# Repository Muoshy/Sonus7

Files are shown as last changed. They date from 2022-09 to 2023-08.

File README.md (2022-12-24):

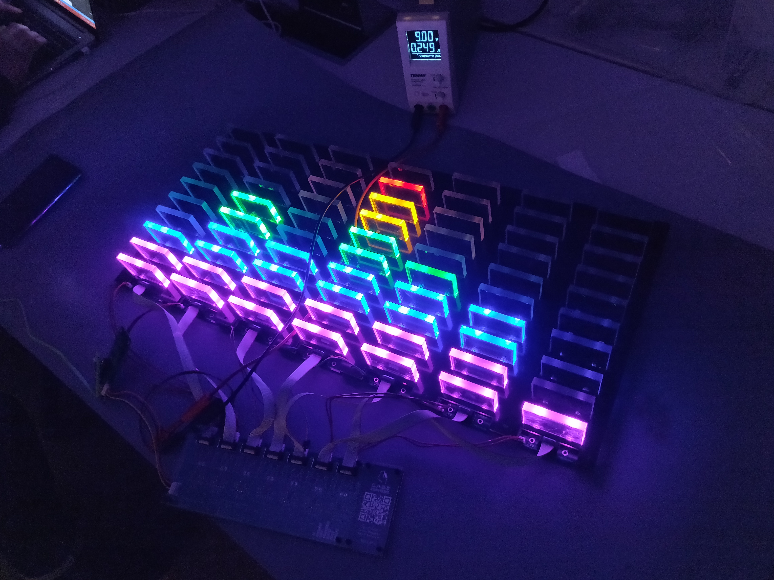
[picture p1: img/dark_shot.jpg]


# Sonus7
  Sonus7 is an analog seven-band spectrum bargraph with op amps. It consists of seven VU-meters, each being fed with a bandpass filter and peak detector circuit. 
  
  Each band has a spacing of 1.25 octaves. The bands are: 63 Hz, 160 Hz, 400 Hz, 1.25 kHz, 2.5 kHz, 6.25 kHz, 16 kHz. 
  
  The filters are second-order Multiple Feedback bandpass filters using TLC272 opamps. The VU-meters consist of a logaritmic comparator array, also using TLC272 opamps. The project is inspired by a reel of 2000 TLC272 bought cheaply at an auction.
  
# Features
- Fully analog (Except input stage)
- Seven frequency bands
- 10 levels per band
- 1.25 octave spacing
- 63 Hz to 16 kHz frequency range

# Filters
The filters were chosen to be Multiple Feedback filters since they allow independent adjustment of the gain $A_m$, filter quality $Q$ and mid frequency $f_m$. The transfer function and equations for calculating component values are taken from TI's design reference SLOD006B (16-31).

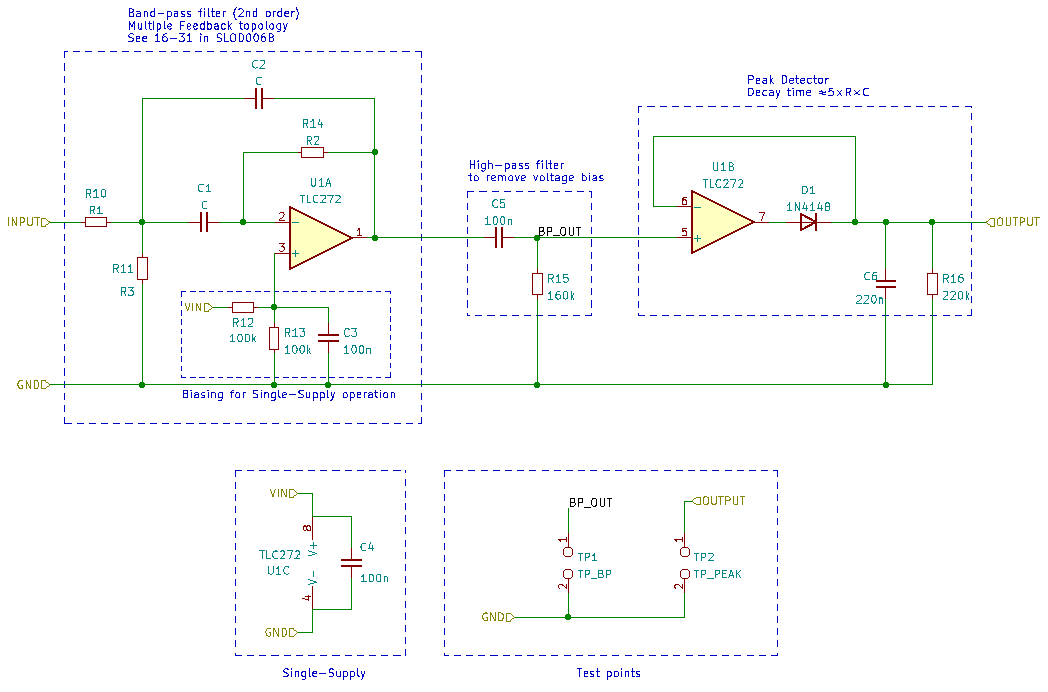
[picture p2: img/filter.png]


The gain and filter quality were set to $A_m = -10, \: Q = 6$ while capacitor values were chosen in the range of 33 to 0.33 nF to end up with reasonable resistor values. A MATLAB script is provided to calculate the exact resistor values and then round to nearest corresponding value from the E-24 series. The frequency responses are then simulated for the exact and rounded resistor values.

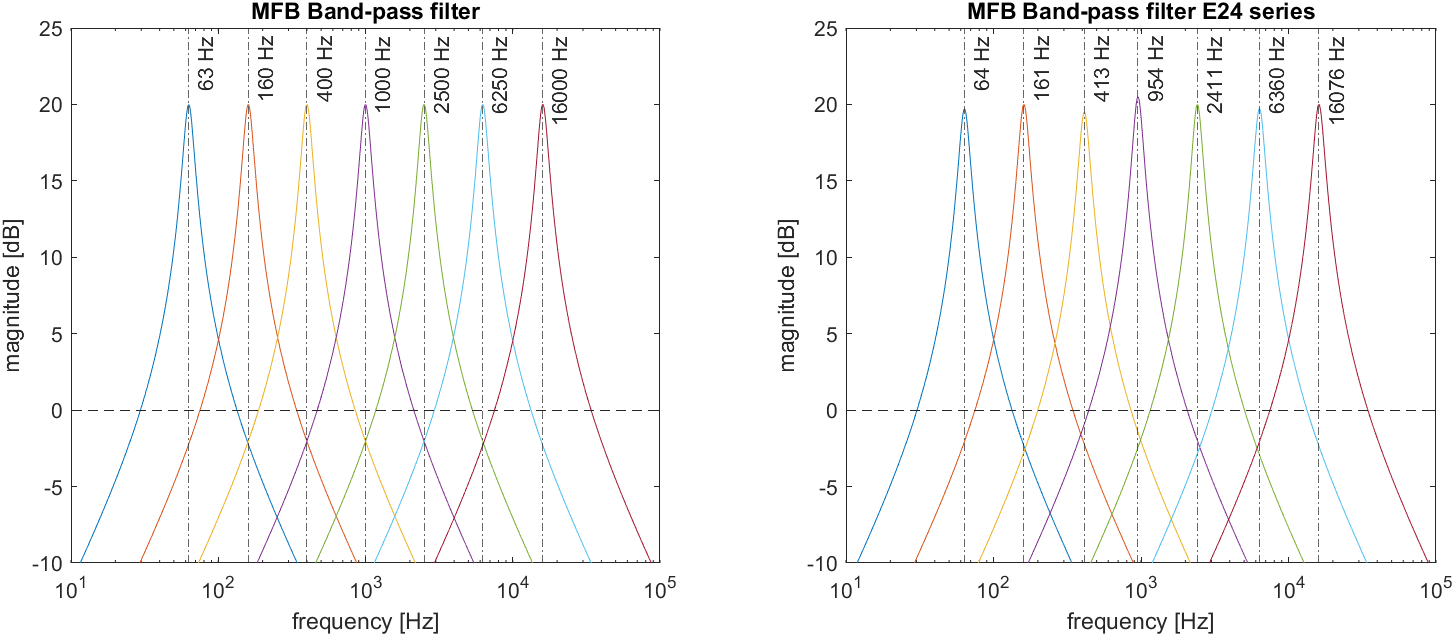
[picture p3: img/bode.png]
bode


A final calculation is done to ensure the filter gains do not exceed the unity gain bandwidth (GBW) of the op amps. The actual amplification from the op amps is obtained from the noise gain. The noise gain is then multiplied with the corresponding mid frequency of each filter to obtain the (highest) GBW. This is also provided in the same MATLAB script. The calculation shows that all filters have a GBW below 2 MHz (TLC272), although the 16 kHz filter is close at 1.1 MHz. Thus, variations in temperature or other factors might limit the gain for 16 kHz filter and cause distortions.

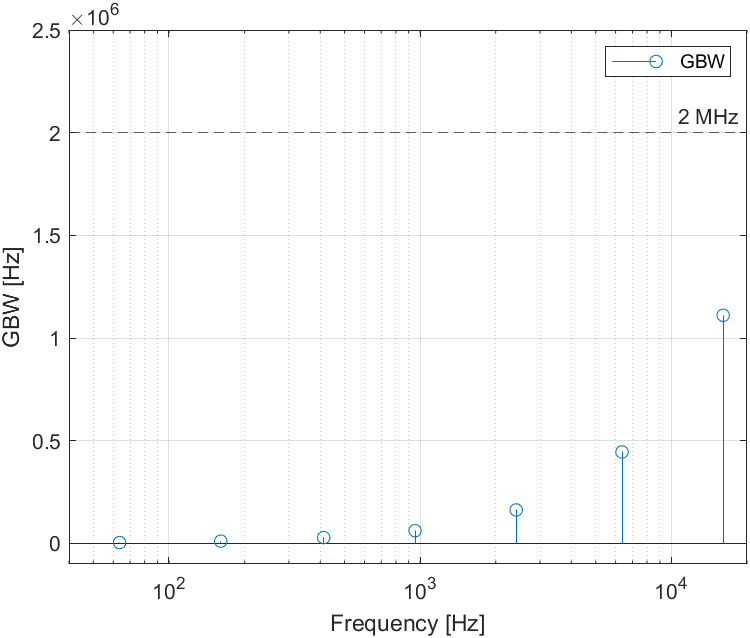
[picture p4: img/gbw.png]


The filtered signals are fed into peak detectors to obtain the audio level for each. The audio levels are then fed into the comparators which control the LEDs.

# Comparators
The comparators are built from open loop op amps. Reference voltage levels are generated from a logarithmic resistor divider (3 dB per step) and fed into the non-inverting inputs, essentially a logarithmic [Kelvin divider](https://en.wikipedia.org/wiki/Kelvin%E2%80%93Varley_divider). The inverting input is fed with the audio level. The op amp output can now function as a current sink for the LEDs. Any time the audio level exceeds the reference voltage level, the output is pulled low, allowing current flow for that level. Each op-amp drives one level, resulting in 70 op amps in total for the comparator stage.

# Construction


## PCBs
The Sonus7 consists of three boards (types).
### Input Stage
 The input stage consists of a custom board with an ESP32 and PCM5100. The ESP32 recieves the audio wirelessly through snapcast, using the port by [@CarlosDerSeher](https://github.com/CarlosDerSeher/snapclientThe). The audio data is then sent to the PCM5100 DAC over I2S. The input stage is connected to the next stage using a 4pin JST EH connector (VCC, GND, MONO, GND). The Kicad files for the input stage are available in /PCBs/ESP-input/.

### Filter and Comparator stage
The filter and comparator stage is the main board and contains all the filters and the comparator arrays. This board also contains the input power DC-jack (9V) along with a simple reverse input protection (PMOS) and thus powers the rest of the boards.

### LED bar
The final stage are the display boards. These are very simple boards with only LEDs, resistors and connectors on them. There is a small cutout on each level for the acrylic diffusers. There are seven of these boards, each one is connected to the main board using an ribbon cable (10p IDC) and a 2p JST cable (9V + GND).

## Mechanical

# Improvements
## Less cables
There is currently a 10p IDC for signal and a 2p JST for power. Combining power and signal into one connector (12p IDC) would tidy up the design.

## More stable supply voltage
Due to varying current draw (LEDs), the Drain-Source resistance of the PMOS causes to a varying voltage drop of 0-22 mV ( $R_{DS}$ = 32 mOhm, $I_{DS}$ = 0.7 A). This can cause issues for the op amps, which need a stable supply voltage. A simple fix could be adding a power regulator after the reverse input protection.

## GBW
The 16 kHz filter is quite close to the rated GBW of the TLC272. There is only a margin of $\frac{2}{1.1} \approx 1.8$ in gain before the limit. This can be solved by using cascaded filters which results in the individual gain of each op amp being smaller. Replacing the TLC272 with higher bandwidth op amps also works.

## Variable brightness
Currently the brightness of the LEDs are set by series resistors. Some brightness control using PWM or some other method could be good for the next version.

# Bill of Materials

# Contributors
**Daniel Quach** ([Muoshy](https://github.com/Muoshy))  
Main Contributor
- Filter design & Simulations
- PCB Design and assembly

**Johan Wheeler** ([johanwheeler](https://github.com/johanwheeler))
- Mechanical design
- Mechanical assembly

**Adam Anderson** ([adand00](https://github.com/adaand00))
- ESP input stage
- PCB Design and programming

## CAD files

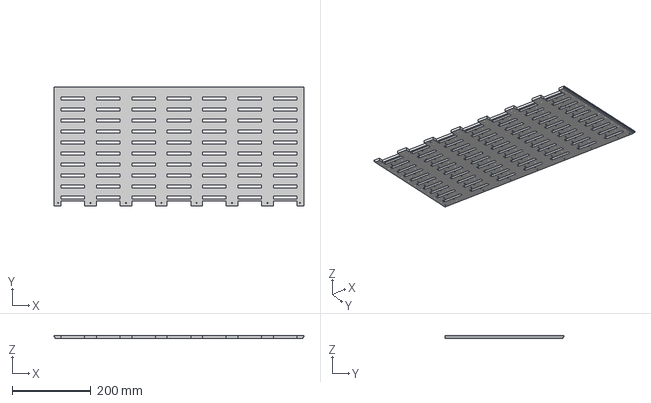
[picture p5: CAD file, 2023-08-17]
CAD/big assembly v14.step
636.0 x 303.0 x 7.00 mm

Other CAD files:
CAD/big assembly v13.f3z

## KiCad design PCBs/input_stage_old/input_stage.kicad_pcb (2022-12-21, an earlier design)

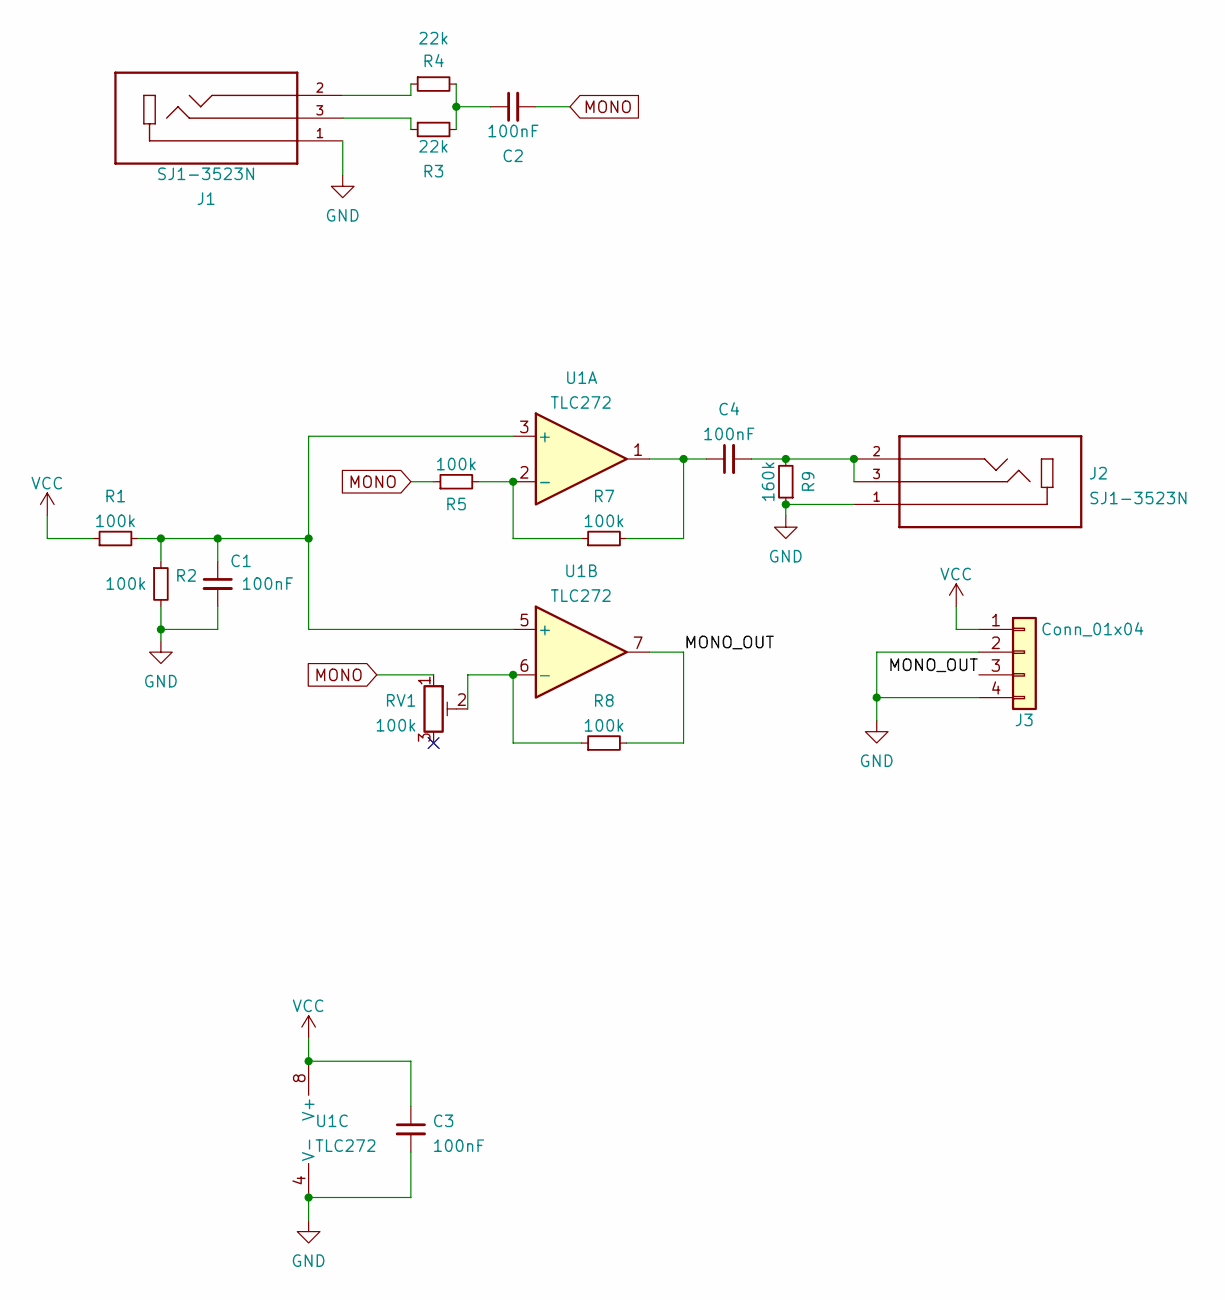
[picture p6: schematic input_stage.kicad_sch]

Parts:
C1, C2, C3, C4: 100nF; C_0603_1608Metric_Pad1.08x0.95mm_HandSolder
J1, J2: SJ1-3523N; CUI_SJ1-3523N; PARTREV 1.02
J3: Conn_01x04; JST_EH_S4B-EH_1x04_P2.50mm_Horizontal
R1, R2, R5, R7, R8: 100k; R_0603_1608Metric_Pad0.98x0.95mm_HandSolder
R3, R4: 22k; R_0603_1608Metric_Pad0.98x0.95mm_HandSolder
R9: 160k; R_0603_1608Metric_Pad0.98x0.95mm_HandSolder
RV1: 100k; Potentiometer_Bourns_TC33X_Vertical
U1: TLC272; SOIC-8_3.9x4.9mm_P1.27mm

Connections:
/MONO_OUT: J3.3, R8.2, U1.7
GND: C1.2, C3.2, J1.1, J2.1, J3.2, J3.4, R2.2, R9.1, U1.4 (V-)
MONO: C2.2, R5.1, RV1.1
unnamed: C1.1, R1.2, R2.1, U1.3 (+), U1.5 (+)
unnamed: C2.1, R3.2, R4.2
unnamed: J1.2, R4.1
unnamed: J1.3, R3.1
unnamed: C4.2, J2.2, J2.3, R9.2
unnamed: R5.2, R7.1, U1.2 (-)
unnamed: C4.1, R7.2, U1.1
unnamed: R8.1, RV1.2, U1.6 (-)
VCC: C3.1, J3.1, R1.1, U1.8 (V+)

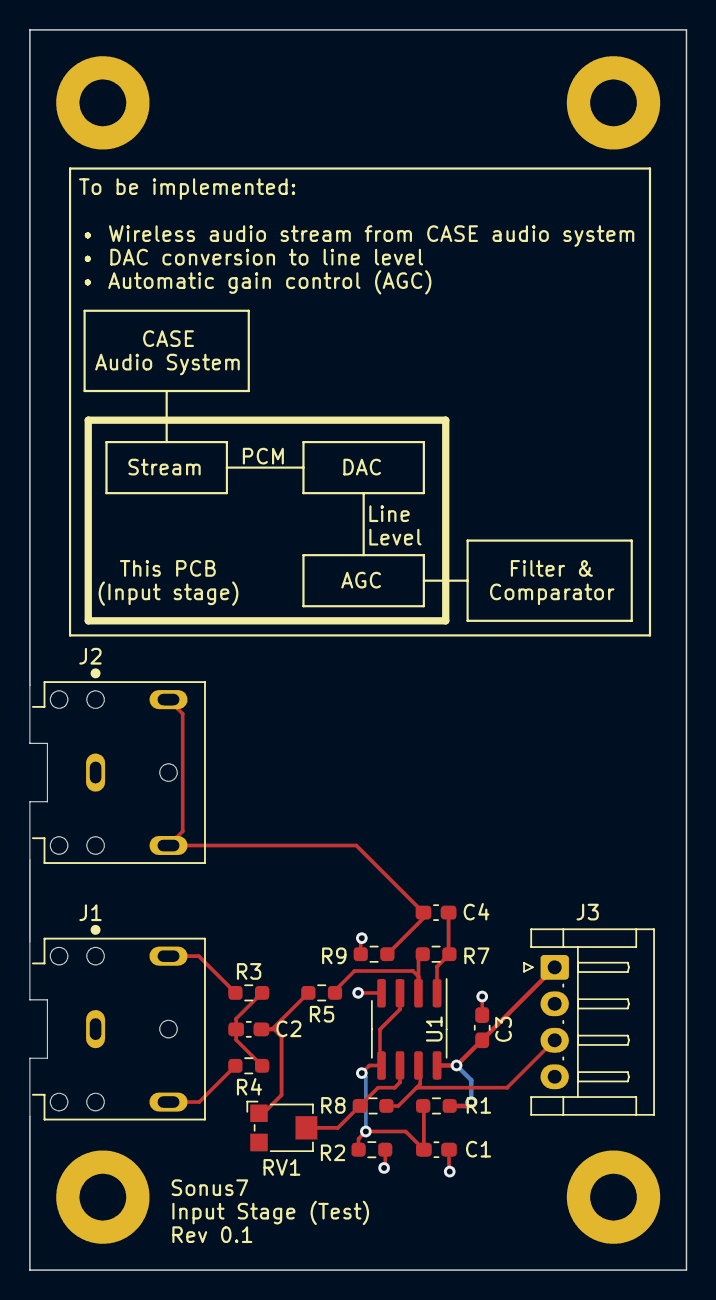
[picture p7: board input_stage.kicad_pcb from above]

Board: 2 copper layers, 45.0 x 85.0 mm, 17 parts (0 on the bottom side), 12 nets.

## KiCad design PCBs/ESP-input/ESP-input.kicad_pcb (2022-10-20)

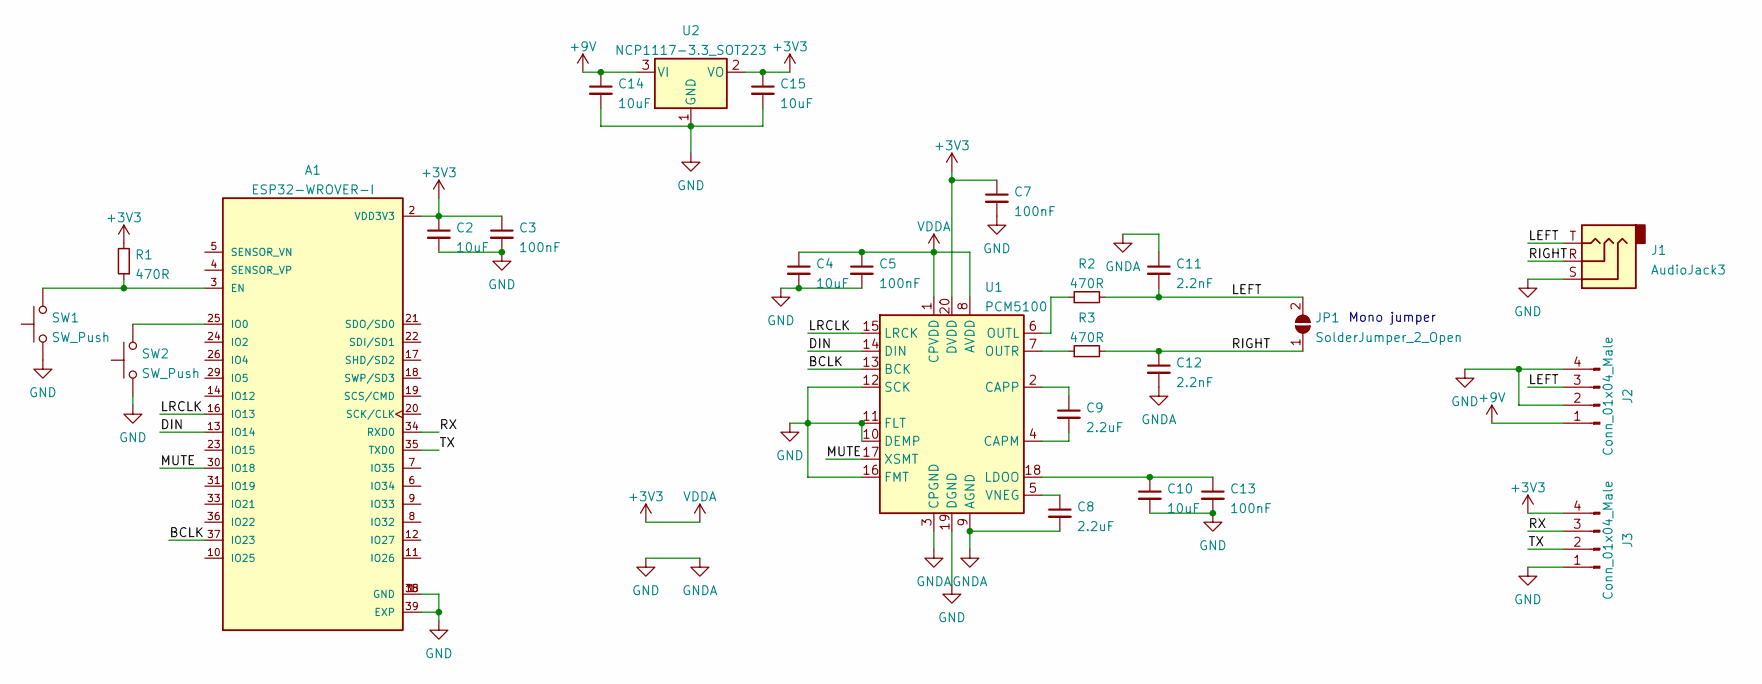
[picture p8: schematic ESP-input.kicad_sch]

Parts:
A1: ESP32-WROVER-I; DIGI-KEY_PART_NUMBER 1904-1008-1-ND
C2, C4, C10, C14, C15: 10uF; C_1206_3216Metric_Pad1.33x1.80mm_HandSolder
C3, C5, C7, C13: 100nF; C_0603_1608Metric_Pad1.08x0.95mm_HandSolder
C8, C9: 2.2uF; C_1206_3216Metric_Pad1.33x1.80mm_HandSolder
C11, C12: 2.2nF; C_0603_1608Metric_Pad1.08x0.95mm_HandSolder
J1: AudioJack3; Jack_3.5mm_CUI_SJ-3523-SMT_Horizontal
J2: Conn_01x04_Male; JST_EH_S4B-EH_1x04_P2.50mm_Horizontal
J3: Conn_01x04_Male; PinHeader_1x04_P2.54mm_Vertical
JP1: SolderJumper_2_Open; SolderJumper-2_P1.3mm_Open_TrianglePad1.0x1.5mm
R1, R2, R3: 470R; R_0603_1608Metric_Pad0.98x0.95mm_HandSolder
SW1, SW2: SW_Push; SW_Push_1P1T_NO_6x6mm_H9.5mm
U1: PCM5100; TSSOP-20_4.4x6.5mm_P0.65mm
U2: NCP1117-3.3_SOT223; SOT-223-3_TabPin2

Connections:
+3V3: A1.2 (VDD3V3), C2.1, C3.1, C4.1, C5.1, C7.1, C15.1, J3.4, R1.2, U1.1 (CPVDD), U1.8 (AVDD), U1.20 (DVDD), U2.2 (VO)
+9V: C14.1, J2.1, U2.3 (VI)
/BCLK: A1.37 (IO23), U1.13 (BCK)
/DIN: A1.13 (IO14), U1.14 (DIN)
/LEFT: C11.2, J1.T, J2.3, JP1.2 (B), R2.2
/LRCLK: A1.16 (IO13), U1.15 (LRCK)
/MUTE: A1.30 (IO18), U1.17 (XSMT)
/RIGHT: C12.1, J1.R, JP1.1 (A), R3.2
/RX: A1.34 (RXD0), J3.3
/TX: A1.35 (TXD0), J3.2
GND: A1.1 (GND), A1.15 (GND), A1.38 (GND), A1.39 (EXP), C2.2, C3.2, C4.2, C5.2, C7.2, C8.2, C10.2, C11.1, C12.2, C13.2, C14.2, C15.2, J1.S, J2.2, J2.4, J3.1, SW1.1, SW2.1, U1.3 (CPGND), U1.9 (AGND), U1.10 (DEMP), U1.11 (FLT), U1.12 (SCK), U1.16 (FMT), U1.19 (DGND), U2.1 (GND)
unnamed: A1.3 (EN), R1.1, SW1.2
unnamed: A1.25 (IO0), SW2.2
unnamed: C8.1, U1.5 (VNEG)
unnamed: C9.1, U1.2 (CAPP)
unnamed: C9.2, U1.4 (CAPM)
unnamed: C10.1, C13.1, U1.18 (LDOO)
unnamed: R2.1, U1.6 (OUTL)
unnamed: R3.1, U1.7 (OUTR)

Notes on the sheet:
Mono jumper

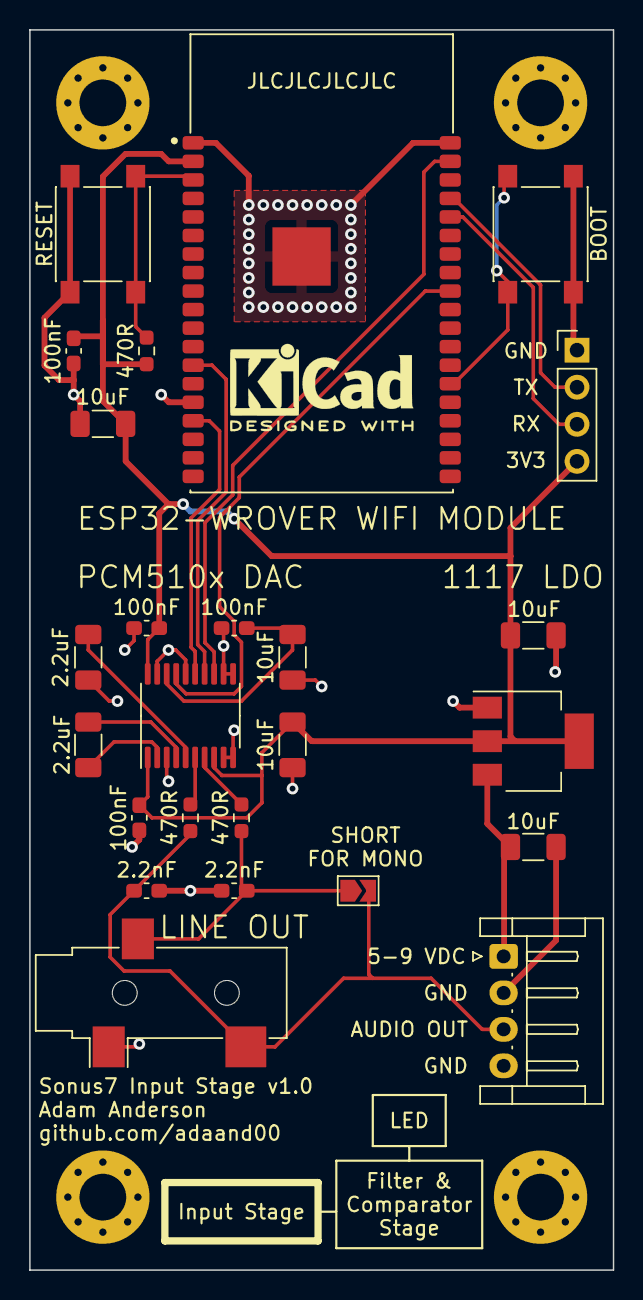
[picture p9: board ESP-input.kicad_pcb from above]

Board: 2 copper layers, 40.0 x 85.0 mm, 25 parts (0 on the bottom side), 19 nets.

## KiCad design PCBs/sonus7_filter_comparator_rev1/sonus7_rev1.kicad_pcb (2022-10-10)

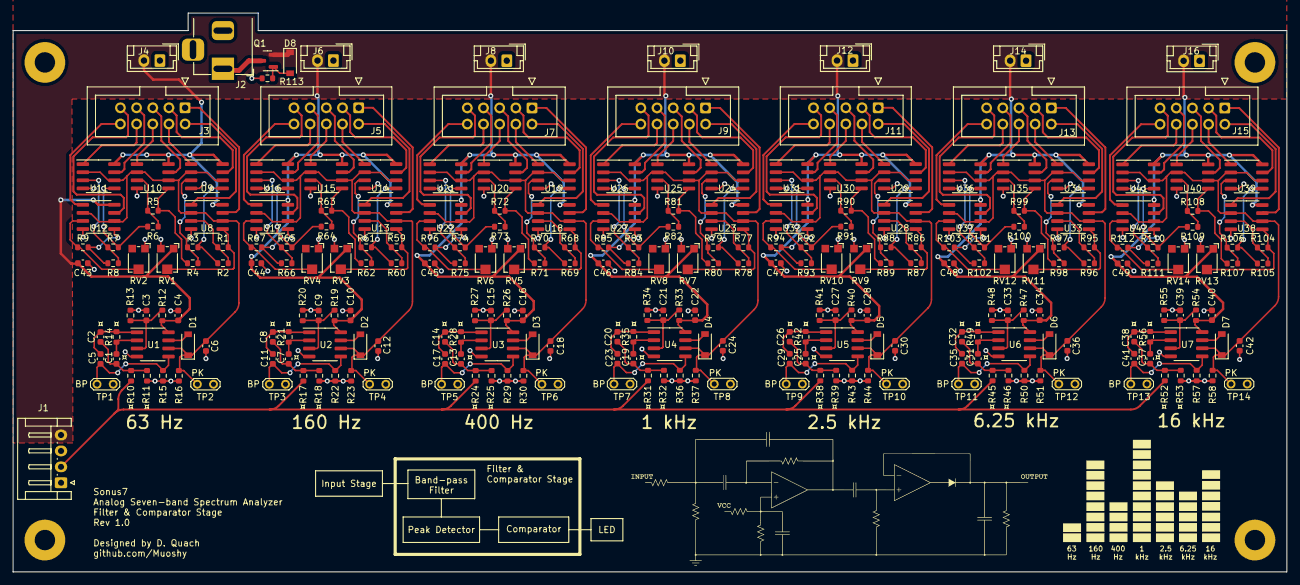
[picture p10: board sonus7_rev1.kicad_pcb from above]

Board: 2 copper layers, 200.0 x 87.8 mm, 257 parts (0 on the bottom side), 194 nets.

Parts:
C1, C2, C7, C8, C13, C14, C19, C20, C25, C26, C31, C32, C37, C38: C; C_0603_1608Metric
C3, C4, C5, C9, C10, C11, C15, C16, C17, C21, C22, C23, C27, C28, C29, C33, C34, C35, C39, C40, C41, C43, C44, C45, C46, C47, C48, C49: 100n; C_0603_1608Metric
C6, C12, C18, C24, C30, C36, C42: 220n; C_0603_1608Metric
D1, D2, D3, D4, D5, D6, D7: 1N4148; D_SOD-123
D8: 8.2V; D_SOD-123
J1: Conn_01x04; JST_EH_S4B-EH_1x04_P2.50mm_Horizontal
J2: DC-Jack; BarrelJack_Horizontal
J3, J5, J7, J9, J11, J13, J15: Conn_02x05_Counter_Clockwise; IDC-Header_2x05_P2.54mm_Vertical
J4, J6, J8, J10, J12, J14, J16: Conn_01x02; JST_EH_B2B-EH-A_1x02_P2.50mm_Vertical
Q1: IRLML6402; SOT-23
R1, R59, R68, R77, R86, R95, R104: 13k; R_0603_1608Metric
R2, R60, R69, R78, R87, R96, R105: 9.1k; R_0603_1608Metric
R3, R61, R70, R79, R88, R97, R106: 6.2k; R_0603_1608Metric
R4, R62, R71, R80, R89, R98, R107: 4.3k; R_0603_1608Metric
R5, R63, R72, R81, R90, R99, R108: 3k; R_0603_1608Metric
R6, R64, R73, R82, R91, R100, R109: 2.2k; R_0603_1608Metric
R7, R65, R74, R83, R92, R101, R110: 1.6k; R_0603_1608Metric
R8, R66, R75, R84, R93, R102, R111: 1.1k; R_0603_1608Metric
R9, R67, R76, R85, R94, R103, R112: 750k; R_0603_1608Metric
R10, R17, R24, R31, R38, R45, R52: R1; R_0603_1608Metric
R11, R18, R25, R32, R39, R46, R53: R3; R_0603_1608Metric
R12, R13, R19, R20, R26, R27, R33, R34, R40, R41, R47, R48, R54, R55: 100k; R_0603_1608Metric
R14, R21, R28, R35, R42, R49, R56: R2; R_0603_1608Metric
R15, R22, R29, R36, R43, R50, R57: 160k; R_0603_1608Metric
R16, R23, R30, R37, R44, R51, R58: 220k; R_0603_1608Metric
R113: 100R; R_0603_1608Metric
RV1, RV3, RV5, RV7, RV9, RV11, RV13: R_U; Potentiometer_Bourns_TC33X_Vertical
RV2, RV4, RV6, RV8, RV10, RV12, RV14: R_L; Potentiometer_Bourns_TC33X_Vertical
TP1, TP3, TP5, TP7, TP9, TP11, TP13: TP_BP; TestPoint_2Pads_Pitch2.54mm_Drill0.8mm
TP2, TP4, TP6, TP8, TP10, TP12, TP14: TP_PEAK; TestPoint_2Pads_Pitch2.54mm_Drill0.8mm
U1, U2, U3, U4, U5, U6, U7, U8, U9, U10, U11, U12, U13, U14, U15, U16, U17, U18, U19, U20, U21, U22, U23, U24, U25, U26, U27, U28, U29, U30, U31, U32, U33, U34, U35, U36, U37, U38, U39, U40, U41, U42: TLC272; SOIC-8_3.9x4.9mm_P1.27mm

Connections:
/Filter 1 kHz/BP_OUT: C23.2, R36.2, TP7.1, U4.5 (+)
/Filter 1 kHz/OUTPUT: C24.2, D4.1 (K), R37.1, TP8.1, U4.6 (-), U23.2 (-), U23.6 (-), U24.2 (-), U24.6 (-), U25.2 (-), U25.6 (-), U26.2 (-), U26.6 (-), U27.2 (-), U27.6 (-)
/Filter 2.5 kHz/BP_OUT: C29.2, R43.2, TP9.1, U5.5 (+)
/Filter 2.5 kHz/OUTPUT: C30.2, D5.1 (K), R44.1, TP10.1, U5.6 (-), U28.2 (-), U28.6 (-), U29.2 (-), U29.6 (-), U30.2 (-), U30.6 (-), U31.2 (-), U31.6 (-), U32.2 (-), U32.6 (-)
/Filter 6.25 kHz/BP_OUT: C35.2, R50.2, TP11.1, U6.5 (+)
/Filter 6.25 kHz/OUTPUT: C36.2, D6.1 (K), R51.1, TP12.1, U6.6 (-), U33.2 (-), U33.6 (-), U34.2 (-), U34.6 (-), U35.2 (-), U35.6 (-), U36.2 (-), U36.6 (-), U37.2 (-), U37.6 (-)
/Filter 16 kHz/BP_OUT: C41.2, R57.2, TP13.1, U7.5 (+)
/Filter 16 kHz/OUTPUT: C42.2, D7.1 (K), R58.1, TP14.1, U7.6 (-), U38.2 (-), U38.6 (-), U39.2 (-), U39.6 (-), U40.2 (-), U40.6 (-), U41.2 (-), U41.6 (-), U42.2 (-), U42.6 (-)
/Filter 63 Hz/BP_OUT: C5.2, R15.2, TP1.1, U1.5 (+)
/Filter 63 Hz/OUTPUT: C6.2, D1.1 (K), R16.1, TP2.1, U1.6 (-), U8.2 (-), U8.6 (-), U9.2 (-), U9.6 (-), U10.2 (-), U10.6 (-), U11.2 (-), U11.6 (-), U12.2 (-), U12.6 (-)
/Filter 160 Hz/BP_OUT: C11.2, R22.2, TP3.1, U2.5 (+)
/Filter 160 Hz/OUTPUT: C12.2, D2.1 (K), R23.1, TP4.1, U2.6 (-), U13.2 (-), U13.6 (-), U14.2 (-), U14.6 (-), U15.2 (-), U15.6 (-), U16.2 (-), U16.6 (-), U17.2 (-), U17.6 (-)
/Filter 400 Hz/BP_OUT: C17.2, R29.2, TP5.1, U3.5 (+)
/Filter 400 Hz/OUTPUT: C18.2, D3.1 (K), R30.1, TP6.1, U3.6 (-), U18.2 (-), U18.6 (-), U19.2 (-), U19.6 (-), U20.2 (-), U20.6 (-), U21.2 (-), U21.6 (-), U22.2 (-), U22.6 (-)
/Log Comp 1 kHz/LV1: R85.1, RV8.2, U27.3 (+)
/Log Comp 1 kHz/LV2: R84.1, R85.2, U27.5 (+)
/Log Comp 1 kHz/LV3: R83.1, R84.2, U26.3 (+)
/Log Comp 1 kHz/LV4: R82.1, R83.2, U26.5 (+)
/Log Comp 1 kHz/LV5: R81.1, R82.2, U25.3 (+)
/Log Comp 1 kHz/LV6: R80.1, R81.2, U25.5 (+)
/Log Comp 1 kHz/LV7: R79.1, R80.2, U24.3 (+)
/Log Comp 1 kHz/LV8: R78.1, R79.2, U24.5 (+)
/Log Comp 1 kHz/LV9: R77.1, R78.2, U23.3 (+)
/Log Comp 1 kHz/LV10: R77.2, RV7.2, U23.5 (+)
/Log Comp 2.5 kHz/LV1: R94.1, RV10.2, U32.3 (+)
/Log Comp 2.5 kHz/LV2: R93.1, R94.2, U32.5 (+)
/Log Comp 2.5 kHz/LV3: R92.1, R93.2, U31.3 (+)
/Log Comp 2.5 kHz/LV4: R91.1, R92.2, U31.5 (+)
/Log Comp 2.5 kHz/LV5: R90.1, R91.2, U30.3 (+)
/Log Comp 2.5 kHz/LV6: R89.1, R90.2, U30.5 (+)
/Log Comp 2.5 kHz/LV7: R88.1, R89.2, U29.3 (+)
/Log Comp 2.5 kHz/LV8: R87.1, R88.2, U29.5 (+)
/Log Comp 2.5 kHz/LV9: R86.1, R87.2, U28.3 (+)
/Log Comp 2.5 kHz/LV10: R86.2, RV9.2, U28.5 (+)
/Log Comp 6.25 kHz/LV1: R103.1, RV12.2, U37.3 (+)
/Log Comp 6.25 kHz/LV2: R102.1, R103.2, U37.5 (+)
/Log Comp 6.25 kHz/LV3: R101.1, R102.2, U36.3 (+)
/Log Comp 6.25 kHz/LV4: R100.1, R101.2, U36.5 (+)
/Log Comp 6.25 kHz/LV5: R99.1, R100.2, U35.3 (+)
/Log Comp 6.25 kHz/LV6: R98.1, R99.2, U35.5 (+)
/Log Comp 6.25 kHz/LV7: R97.1, R98.2, U34.3 (+)
/Log Comp 6.25 kHz/LV8: R96.1, R97.2, U34.5 (+)
/Log Comp 6.25 kHz/LV9: R95.1, R96.2, U33.3 (+)
/Log Comp 6.25 kHz/LV10: R95.2, RV11.2, U33.5 (+)
/Log Comp 16 kHz/LV1: R112.1, RV14.2, U42.3 (+)
/Log Comp 16 kHz/LV2: R111.1, R112.2, U42.5 (+)
/Log Comp 16 kHz/LV3: R110.1, R111.2, U41.3 (+)
/Log Comp 16 kHz/LV4: R109.1, R110.2, U41.5 (+)
/Log Comp 16 kHz/LV5: R108.1, R109.2, U40.3 (+)
/Log Comp 16 kHz/LV6: R107.1, R108.2, U40.5 (+)
/Log Comp 16 kHz/LV7: R106.1, R107.2, U39.3 (+)
/Log Comp 16 kHz/LV8: R105.1, R106.2, U39.5 (+)
/Log Comp 16 kHz/LV9: R104.1, R105.2, U38.3 (+)
/Log Comp 16 kHz/LV10: R104.2, RV13.2, U38.5 (+)
/Log Comp 63 Hz/LV1: R9.1, RV2.2, U12.3 (+)
/Log Comp 63 Hz/LV2: R8.1, R9.2, U12.5 (+)
/Log Comp 63 Hz/LV3: R7.1, R8.2, U11.3 (+)
/Log Comp 63 Hz/LV4: R6.1, R7.2, U11.5 (+)
/Log Comp 63 Hz/LV5: R5.1, R6.2, U10.3 (+)
/Log Comp 63 Hz/LV6: R4.1, R5.2, U10.5 (+)
/Log Comp 63 Hz/LV7: R3.1, R4.2, U9.3 (+)
/Log Comp 63 Hz/LV8: R2.1, R3.2, U9.5 (+)
/Log Comp 63 Hz/LV9: R1.1, R2.2, U8.3 (+)
/Log Comp 63 Hz/LV10: R1.2, RV1.2, U8.5 (+)
/Log Comp 160 Hz/LV1: R67.1, RV4.2, U17.3 (+)
/Log Comp 160 Hz/LV2: R66.1, R67.2, U17.5 (+)
/Log Comp 160 Hz/LV3: R65.1, R66.2, U16.3 (+)
/Log Comp 160 Hz/LV4: R64.1, R65.2, U16.5 (+)
/Log Comp 160 Hz/LV5: R63.1, R64.2, U15.3 (+)
/Log Comp 160 Hz/LV6: R62.1, R63.2, U15.5 (+)
/Log Comp 160 Hz/LV7: R61.1, R62.2, U14.3 (+)
/Log Comp 160 Hz/LV8: R60.1, R61.2, U14.5 (+)
/Log Comp 160 Hz/LV9: R59.1, R60.2, U13.3 (+)
/Log Comp 160 Hz/LV10: R59.2, RV3.2, U13.5 (+)
/Log Comp 400 Hz/LV1: R76.1, RV6.2, U22.3 (+)
/Log Comp 400 Hz/LV2: R75.1, R76.2, U22.5 (+)
/Log Comp 400 Hz/LV3: R74.1, R75.2, U21.3 (+)
/Log Comp 400 Hz/LV4: R73.1, R74.2, U21.5 (+)
/Log Comp 400 Hz/LV5: R72.1, R73.2, U20.3 (+)
/Log Comp 400 Hz/LV6: R71.1, R72.2, U20.5 (+)
/Log Comp 400 Hz/LV7: R70.1, R71.2, U19.3 (+)
/Log Comp 400 Hz/LV8: R69.1, R70.2, U19.5 (+)
/Log Comp 400 Hz/LV9: R68.1, R69.2, U18.3 (+)
/Log Comp 400 Hz/LV10: R68.2, RV5.2, U18.5 (+)
/PWR_IN: J2.1, Q1.3 (D)
GND: C3.2, C4.2, C6.1, C9.2, C10.2, C12.1, C15.2, C16.2, C18.1, C21.2, C22.2, C24.1, C27.2, C28.2, C30.1, C33.2, C34.2, C36.1, C39.2, C40.2, C42.1, C43.2, C44.2, C45.2, C46.2, C47.2, C48.2, C49.2, J1.1, J1.3, J2.2, J2.3, J4.1, J6.1, J8.1, J10.1, J12.1, J14.1, J16.1, R11.2, R13.2, R15.1, R16.2, R18.2, R20.2, R22.1, R23.2, R25.2, R27.2, R29.1, R30.2, R32.2, R34.2, R36.1, R37.2, R39.2, R41.2, R43.1, R44.2, R46.2, R48.2, R50.1, R51.2, R53.2, R55.2, R57.1, R58.2, R113.2, RV1.3, RV2.1, RV3.3, RV4.1, RV5.3, RV6.1, RV7.3, RV8.1, RV9.3, RV10.1, RV11.3, RV12.1, RV13.3, RV14.1, TP1.2, TP2.2, TP3.2, TP4.2, TP5.2, TP6.2, TP7.2, TP8.2, TP9.2, TP10.2, TP11.2, TP12.2, TP13.2, TP14.2, U1.4 (V-), U2.4 (V-), U3.4 (V-), U4.4 (V-), U5.4 (V-), U6.4 (V-), U7.4 (V-), U8.4 (V-), U9.4 (V-), U10.4 (V-), U11.4 (V-), U12.4 (V-), U13.4 (V-), U14.4 (V-), U15.4 (V-), U16.4 (V-), U17.4 (V-), U18.4 (V-), U19.4 (V-), U20.4 (V-), U21.4 (V-), U22.4 (V-), U23.4 (V-), U24.4 (V-), U25.4 (V-), U26.4 (V-), U27.4 (V-), U28.4 (V-), U29.4 (V-), U30.4 (V-), U31.4 (V-), U32.4 (V-), U33.4 (V-), U34.4 (V-), U35.4 (V-), U36.4 (V-), U37.4 (V-), U38.4 (V-), U39.4 (V-), U40.4 (V-), U41.4 (V-), U42.4 (V-)
MONO: J1.2, R10.1, R17.1, R24.1, R31.1, R38.1, R45.1, R52.1
unnamed: C1.1, C2.1, R10.2, R11.1
unnamed: C1.2, R14.1, U1.2 (-)
unnamed: C2.2, C5.1, R14.2, U1.1
unnamed: C3.1, R12.2, R13.1, U1.3 (+)
unnamed: C7.1, C8.1, R17.2, R18.1
unnamed: C7.2, R21.1, U2.2 (-)
unnamed: C9.1, R19.2, R20.1, U2.3 (+)
unnamed: C8.2, C11.1, R21.2, U2.1
unnamed: C13.1, C14.1, R24.2, R25.1
unnamed: C13.2, R28.1, U3.2 (-)
unnamed: C14.2, C17.1, R28.2, U3.1
unnamed: C15.1, R26.2, R27.1, U3.3 (+)
unnamed: C19.1, C20.1, R31.2, R32.1
unnamed: C19.2, R35.1, U4.2 (-)
unnamed: C20.2, C23.1, R35.2, U4.1
unnamed: C21.1, R33.2, R34.1, U4.3 (+)
unnamed: C25.1, C26.1, R38.2, R39.1
unnamed: C25.2, R42.1, U5.2 (-)
unnamed: C26.2, C29.1, R42.2, U5.1
unnamed: C27.1, R40.2, R41.1, U5.3 (+)
unnamed: C31.1, C32.1, R45.2, R46.1
unnamed: C31.2, R49.1, U6.2 (-)
unnamed: C32.2, C35.1, R49.2, U6.1
unnamed: C33.1, R47.2, R48.1, U6.3 (+)
unnamed: C37.1, C38.1, R52.2, R53.1
unnamed: C37.2, R56.1, U7.2 (-)
unnamed: C38.2, C41.1, R56.2, U7.1
unnamed: C39.1, R54.2, R55.1, U7.3 (+)
unnamed: D1.2 (A), U1.7
unnamed: D2.2 (A), U2.7
unnamed: D3.2 (A), U3.7
unnamed: D4.2 (A), U4.7
unnamed: D5.2 (A), U5.7
unnamed: D6.2 (A), U6.7
unnamed: D7.2 (A), U7.7
unnamed: D8.2 (A), Q1.1 (G), R113.1
unnamed: J3.1, U8.7
unnamed: J3.2, U8.1
unnamed: J3.3, U9.7
unnamed: J3.4, U9.1
unnamed: J3.5, U10.7
unnamed: J3.6, U10.1
unnamed: J3.7, U11.7
unnamed: J3.8, U11.1
unnamed: J3.9, U12.7
unnamed: J3.10, U12.1
unnamed: J5.1, U13.7
unnamed: J5.2, U13.1
unnamed: J5.3, U14.7
unnamed: J5.4, U14.1
unnamed: J5.5, U15.7
unnamed: J5.6, U15.1
unnamed: J5.7, U16.7
unnamed: J5.8, U16.1
unnamed: J5.9, U17.7
unnamed: J5.10, U17.1
unnamed: J7.1, U18.7
unnamed: J7.2, U18.1
unnamed: J7.3, U19.7
unnamed: J7.4, U19.1
unnamed: J7.5, U20.7
unnamed: J7.6, U20.1
unnamed: J7.7, U21.7
unnamed: J7.8, U21.1
unnamed: J7.9, U22.7
unnamed: J7.10, U22.1
unnamed: J9.1, U23.7
unnamed: J9.2, U23.1
unnamed: J9.3, U24.7
unnamed: J9.4, U24.1
unnamed: J9.5, U25.7
unnamed: J9.6, U25.1
unnamed: J9.7, U26.7
unnamed: J9.8, U26.1
unnamed: J9.9, U27.7
unnamed: J9.10, U27.1
unnamed: J11.1, U28.7
unnamed: J11.2, U28.1
unnamed: J11.3, U29.7
unnamed: J11.4, U29.1
unnamed: J11.5, U30.7
unnamed: J11.6, U30.1
unnamed: J11.7, U31.7
unnamed: J11.8, U31.1
unnamed: J11.9, U32.7
unnamed: J11.10, U32.1
unnamed: J13.1, U33.7
unnamed: J13.2, U33.1
unnamed: J13.3, U34.7
unnamed: J13.4, U34.1
unnamed: J13.5, U35.7
unnamed: J13.6, U35.1
unnamed: J13.7, U36.7
unnamed: J13.8, U36.1
unnamed: J13.9, U37.7
unnamed: J13.10, U37.1
unnamed: J15.1, U38.7
unnamed: J15.2, U38.1
unnamed: J15.3, U39.7
unnamed: J15.4, U39.1
unnamed: J15.5, U40.7
unnamed: J15.6, U40.1
unnamed: J15.7, U41.7
unnamed: J15.8, U41.1
unnamed: J15.9, U42.7
unnamed: J15.10, U42.1
VCC: C4.1, C10.1, C16.1, C22.1, C28.1, C34.1, C40.1, C43.1, C44.1, C45.1, C46.1, C47.1, C48.1, C49.1, D8.1 (K), J1.4, J4.2, J6.2, J8.2, J10.2, J12.2, J14.2, J16.2, Q1.2 (S), R12.1, R19.1, R26.1, R33.1, R40.1, R47.1, R54.1, RV1.1, RV3.1, RV5.1, RV7.1, RV9.1, RV11.1, RV13.1, U1.8 (V+), U2.8 (V+), U3.8 (V+), U4.8 (V+), U5.8 (V+), U6.8 (V+), U7.8 (V+), U8.8 (V+), U9.8 (V+), U10.8 (V+), U11.8 (V+), U12.8 (V+), U13.8 (V+), U14.8 (V+), U15.8 (V+), U16.8 (V+), U17.8 (V+), U18.8 (V+), U19.8 (V+), U20.8 (V+), U21.8 (V+), U22.8 (V+), U23.8 (V+), U24.8 (V+), U25.8 (V+), U26.8 (V+), U27.8 (V+), U28.8 (V+), U29.8 (V+), U30.8 (V+), U31.8 (V+), U32.8 (V+), U33.8 (V+), U34.8 (V+), U35.8 (V+), U36.8 (V+), U37.8 (V+), U38.8 (V+), U39.8 (V+), U40.8 (V+), U41.8 (V+), U42.8 (V+)

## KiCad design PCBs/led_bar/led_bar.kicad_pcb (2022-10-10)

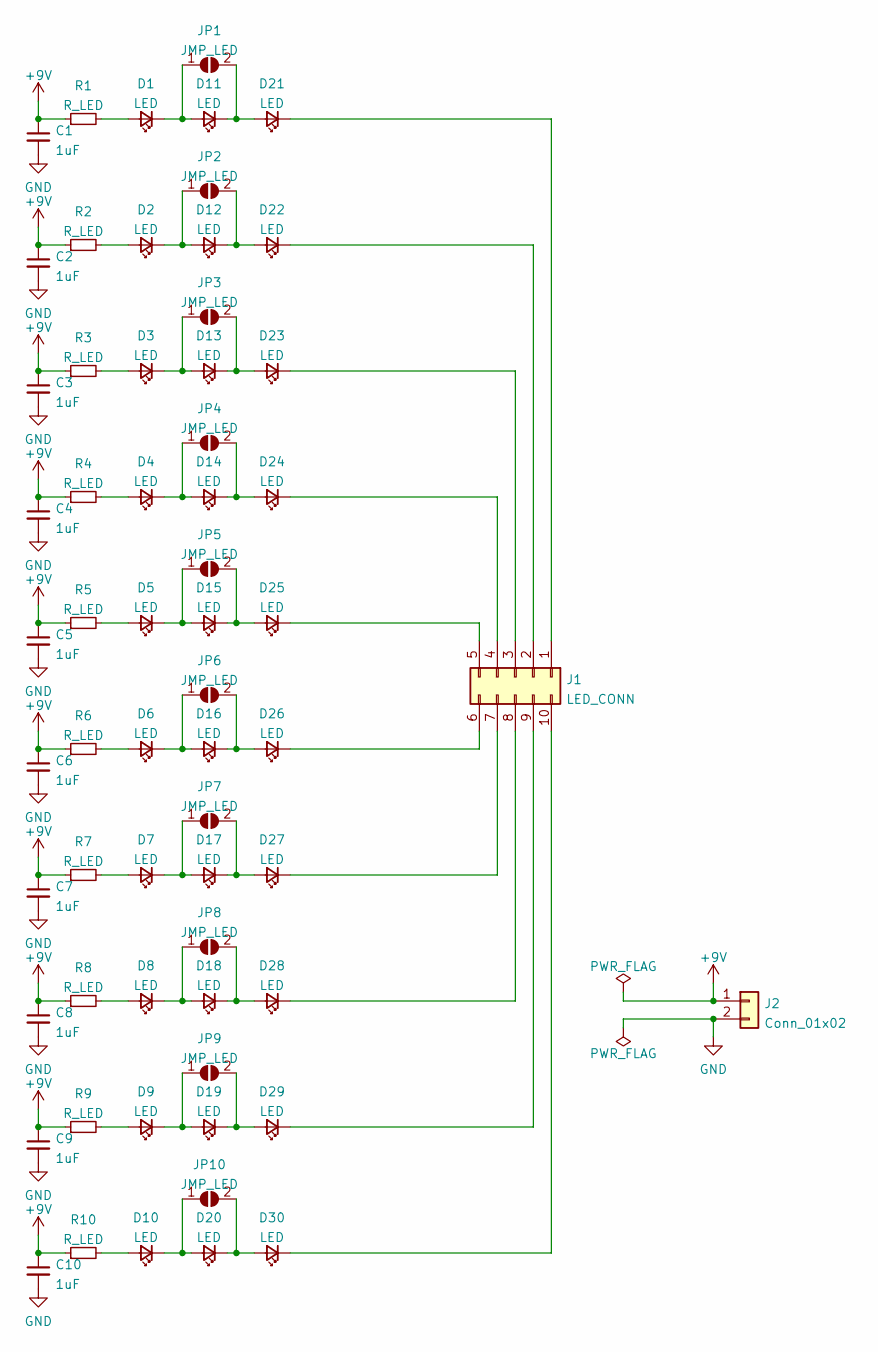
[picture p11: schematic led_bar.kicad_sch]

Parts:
C1, C2, C3, C4, C5, C6, C7, C8, C9, C10: 1uF; C_0805_2012Metric_Pad1.18x1.45mm_HandSolder
D1, D2, D3, D4, D5, D6, D7, D8, D9, D10, D11, D12, D13, D14, D15, D16, D17, D18, D19, D20, D21, D22, D23, D24, D25, D26, D27, D28, D29, D30: LED; LED_5mm_DUAL
J1: LED_CONN; IDC-Header_2x05_P2.54mm_Vertical
J2: Conn_01x02; JST_EH_B2B-EH-A_1x02_P2.50mm_Vertical
JP1, JP2, JP3, JP4, JP5, JP6, JP7, JP8, JP9, JP10: JMP_LED; SolderJumper-2_P1.3mm_Open_TrianglePad1.0x1.5mm
R1, R2, R3, R4, R5, R6, R7, R8, R9, R10: R_LED; R_0805_2012Metric_Pad1.20x1.40mm_HandSolder

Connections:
+9V: C1.1, C2.1, C3.1, C4.1, C5.1, C6.1, C7.1, C8.1, C9.1, C10.1, J2.1, R1.1, R2.1, R3.1, R4.1, R5.1, R6.1, R7.1, R8.1, R9.1, R10.1
GND: C1.2, C2.2, C3.2, C4.2, C5.2, C6.2, C7.2, C8.2, C9.2, C10.2, J2.2
unnamed: D1.1 (K), D11.2 (A), JP1.1 (A)
unnamed: D1.2 (A), R1.2
unnamed: D2.2 (A), R2.2
unnamed: D3.2 (A), R3.2
unnamed: D4.2 (A), R4.2
unnamed: D5.2 (A), R5.2
unnamed: D6.2 (A), R6.2
unnamed: D7.2 (A), R7.2
unnamed: D8.2 (A), R8.2
unnamed: D9.2 (A), R9.2
unnamed: D10.1 (K), D20.2 (A), JP10.1 (A)
unnamed: D10.2 (A), R10.2
unnamed: D11.1 (K), D21.2 (A), JP1.2 (B)
unnamed: D12.1 (K), D22.2 (A), JP2.2 (B)
unnamed: D2.1 (K), D12.2 (A), JP2.1 (A)
unnamed: D13.1 (K), D23.2 (A), JP3.2 (B)
unnamed: D3.1 (K), D13.2 (A), JP3.1 (A)
unnamed: D14.1 (K), D24.2 (A), JP4.2 (B)
unnamed: D4.1 (K), D14.2 (A), JP4.1 (A)
unnamed: D15.1 (K), D25.2 (A), JP5.2 (B)
unnamed: D5.1 (K), D15.2 (A), JP5.1 (A)
unnamed: D16.1 (K), D26.2 (A), JP6.2 (B)
unnamed: D6.1 (K), D16.2 (A), JP6.1 (A)
unnamed: D17.1 (K), D27.2 (A), JP7.2 (B)
unnamed: D7.1 (K), D17.2 (A), JP7.1 (A)
unnamed: D18.1 (K), D28.2 (A), JP8.2 (B)
unnamed: D8.1 (K), D18.2 (A), JP8.1 (A)
unnamed: D19.1 (K), D29.2 (A), JP9.2 (B)
unnamed: D9.1 (K), D19.2 (A), JP9.1 (A)
unnamed: D20.1 (K), D30.2 (A), JP10.2 (B)
unnamed: D21.1 (K), J1.1
unnamed: D22.1 (K), J1.2
unnamed: D23.1 (K), J1.3
unnamed: D24.1 (K), J1.4
unnamed: D25.1 (K), J1.5
unnamed: D26.1 (K), J1.6
unnamed: D27.1 (K), J1.7
unnamed: D28.1 (K), J1.8
unnamed: D29.1 (K), J1.9
unnamed: D30.1 (K), J1.10

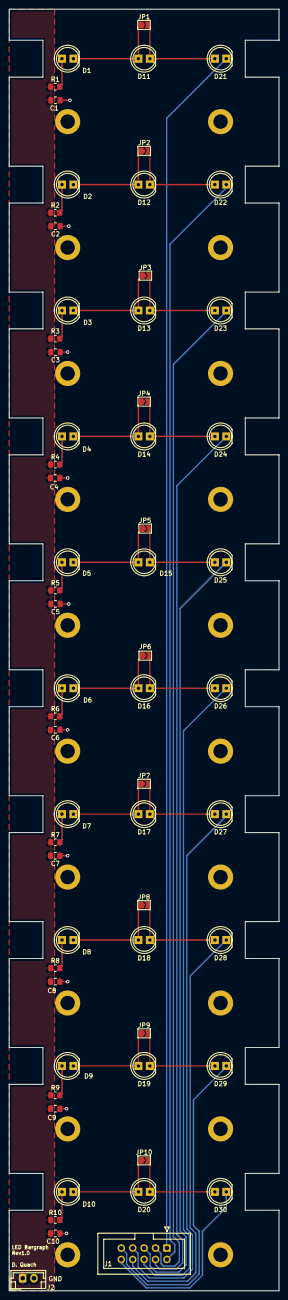
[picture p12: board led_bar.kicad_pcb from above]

Board: 2 copper layers, 60.0 x 285.0 mm, 62 parts (0 on the bottom side), 42 nets.

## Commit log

2022-09-23 Upload MATLAB script MFB_BP_SIM.m
    MATLAB script for calculating filter parameters and simulations
2022-10-10 Add LED bar files
    [led_bar-B_Cu.gbl, led_bar-B_Mask.gbs, led_bar-B_Paste.gbp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]
2022-10-10 Add Filter & comparator files
    [comp_stage.kicad_sch, filter_stage.kicad_sch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]
2022-10-20 ESP-input v1.0
    [ESP-input-B_Cu.gbr, ESP-input-B_Mask.gbr, ESP-input-B_Paste.gbr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]
2022-10-20 Add Zipped GRBs
    [ESP-input.kicad_pcb]
2022-11-01 add filter img
2022-11-21 Add info bout input stage
2022-12-21 Added files for old input stage
    [input_stage-B_Cu.gbl, input_stage-B_Mask.gbs, input_stage-B_Paste.gbp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]
2023-08-17 Added some cad files
    [big assembly v13.f3z, big assembly v14.step]
